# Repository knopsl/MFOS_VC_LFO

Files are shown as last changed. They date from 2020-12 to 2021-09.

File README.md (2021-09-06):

# MFOS VC LFO sync mod, pulse width fix, and Kosmo panel

This is a couple of modifications for the MFOS VC LFO and a Kosmo format front panel. One mod is component value changes, described below, that correct some undesired behavior having to do with the pulse width. The other is an auxiliary PCB that adds a sync input as well as a Euro/Kosmo style power header.

## Sync input

The auxiliary board adds a sync input. A rising edge on this input resets the LFO's triangle core to either the maximum or the minimum peak (switch selectable). This allows LFO modulation to begin in sync with e.g. the start of a note. Other outputs also are synced at either the "beginning" or the "midpoint" (in time) of the waveform.

This modification is based on Tim Parkhurst's [sync mod](https://electro-music.com/forum/post-387749.html#387749).  I added a switch to select whether to charge the triangle core to its maximum or minimum value, affecting where in each waveform sync occurs. Resistances were changed to accommodate the MFOS LFO's larger integrating capacitor, and I used J113 for the JFET instead of 2N3819. 2N5458 was also found to work, J112 did not. One resistor was made a trimmer to allow tuning the voltage to which the oscillator resets. It should be adjusted until the triangle wave is at its maximum or minimum immediately after syncing.

The auxiliary board also has footprints for a Eurorack style power header with reversal protection diodes and bypass capacitors (which should be mounted there instead of on the MFOS board) and a terminal block. Wires from the terminal block connect to ±12 V and ground on the MFOS board. Molex connectors are used to connect the sync mod to the panel controls and PCB.

## Pulse width fixes

As designed, the MFOS LFO has some undesireable behavior with the pulse width. The PW CV input floats when nothing is plugged in, meaning that the pulse width and its range are different with no CV input versus with 0V CV input. Also, since the PW pot and its associated fixed resistors are large compared to the summing resistors, an attenuator on the PW CV (external or added to the front panel) will affect the behavior of the pulse width pot and vice versa.

I recommend the following changes:

* R37 (pulse width pot) from 100k to 25k
* R36 and R42 (fixed resistors at ends of R37) from 100k to 3.3k
* R58 and R59 (summing resistors) from 10k to 200k

With these changes I find the effects of the PW pot on the PW CV attenuator and vice versa are negligible, and I get a pulse width range from the knob (with no CV) of about 7% to 91%. 

## Front panel

A Kosmo format front panel is also provided. It includes space for the attenuator pots for the FM 1 and PWM control voltages. Width is 10 cm.

## Sync mod documentation

* [Build notes](Docs/build_notes.md) 
* [BOM](Docs/MFOS_VCLFO_aux.pdf) (See above for changes to the main PCB BOM.)
* [Schematics](Docs/MFOS_VCLFO_aux.pdf) 

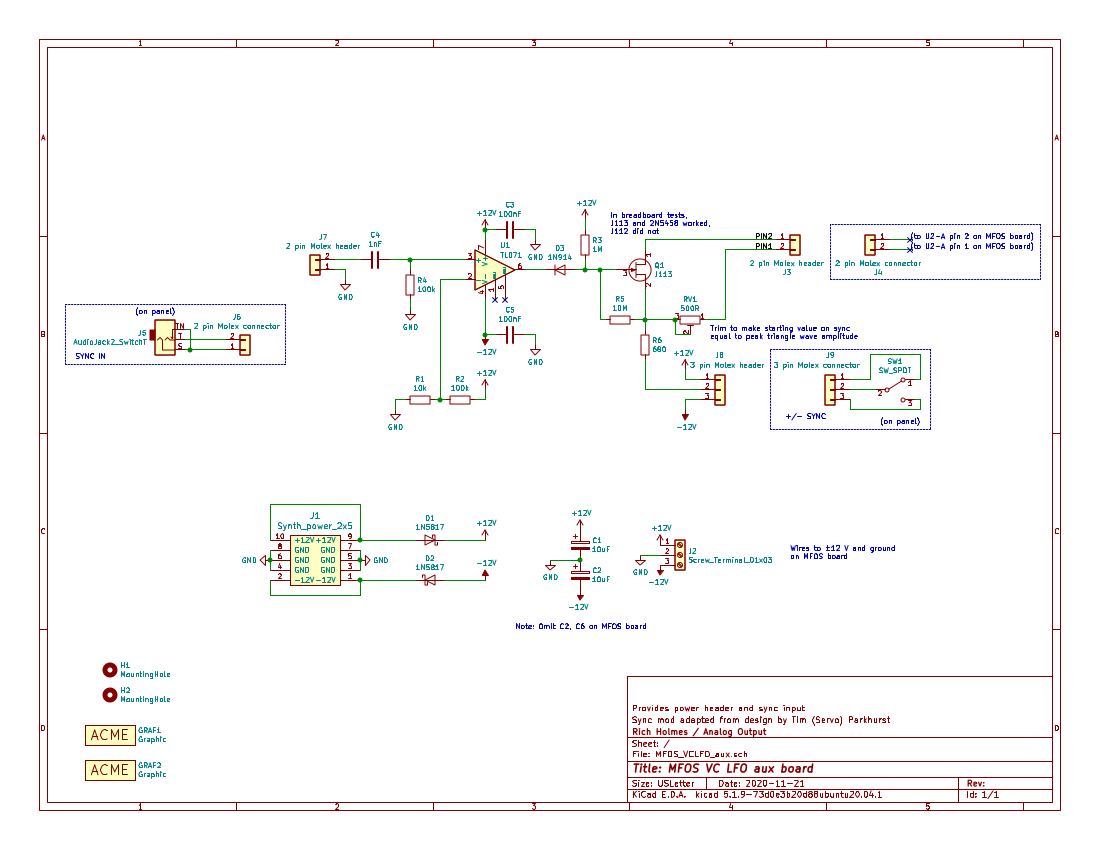
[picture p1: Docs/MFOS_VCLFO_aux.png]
Auxiliary PCB

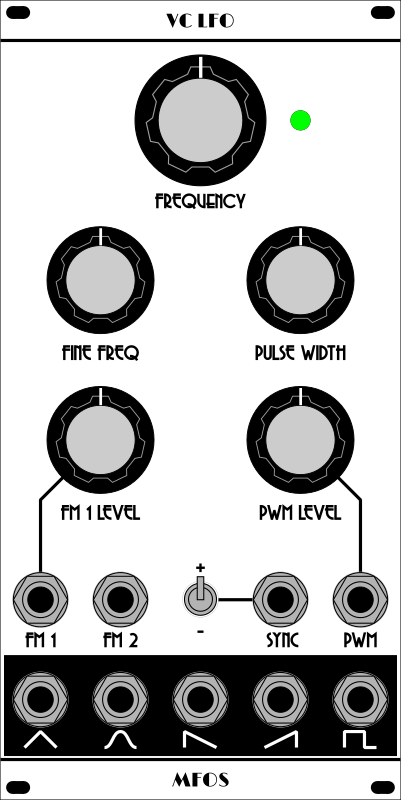
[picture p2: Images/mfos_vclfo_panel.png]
Kosmo front panel


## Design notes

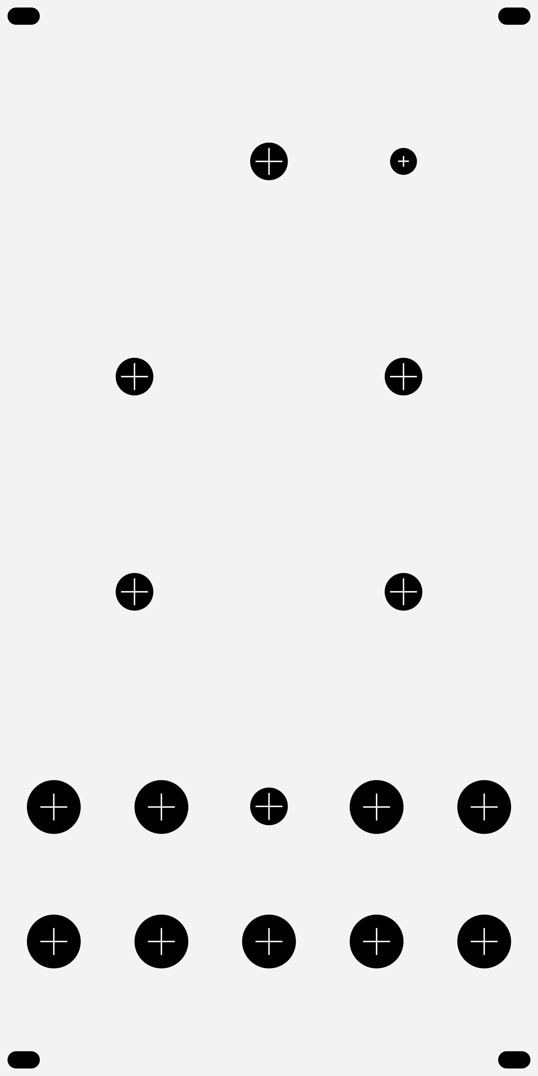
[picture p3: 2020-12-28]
Hardware/Panel/mfos_vclfo_panel_holes.png

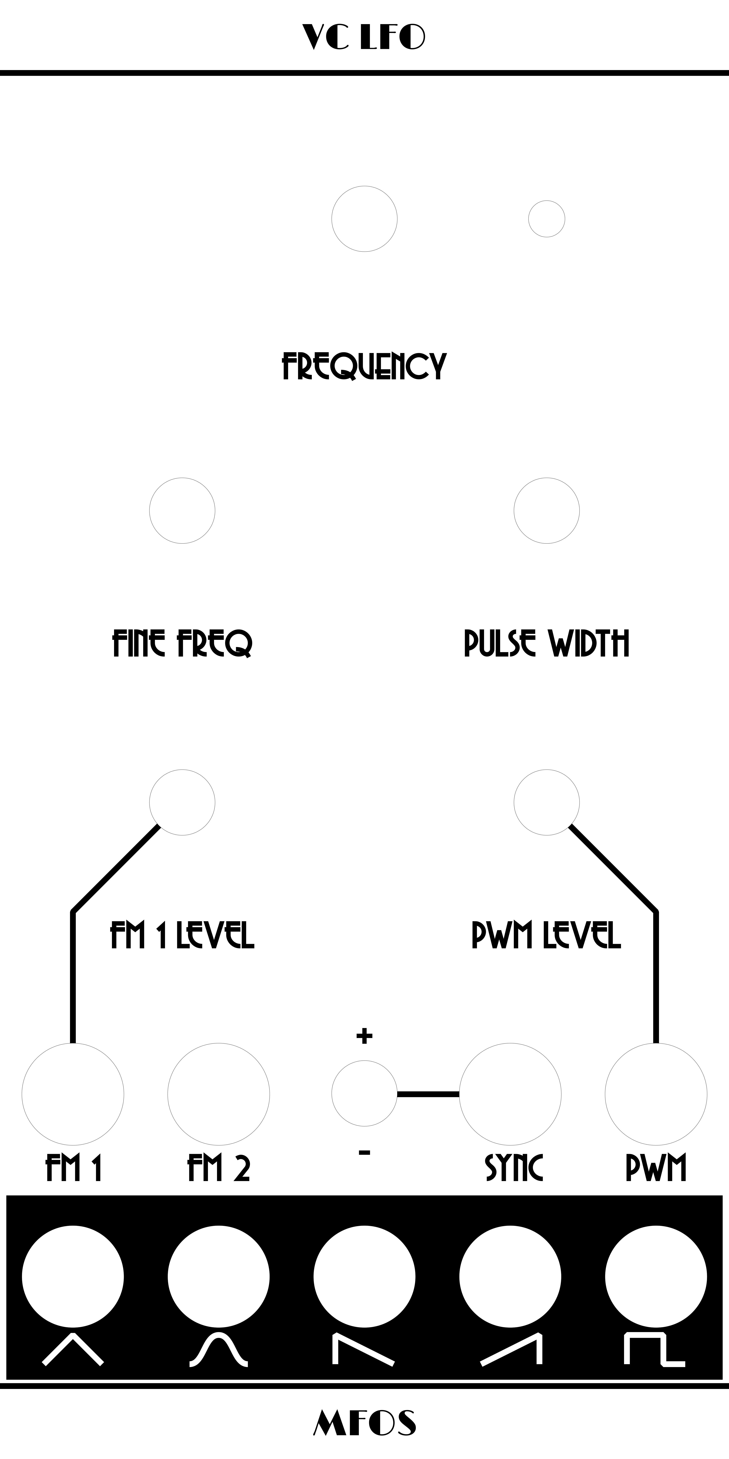
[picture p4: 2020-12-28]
Images/mfos_vclfo_panel_art.png

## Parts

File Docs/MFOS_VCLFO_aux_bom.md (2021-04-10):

# Auxiliary board for MFOS VC LFO BOM

Wed 31 Mar 2021 05:28:39 PM EDT

Generated from schematic by Eeschema 5.1.9-73d0e3b20d~88~ubuntu20.04.1

**Component Count:** 27

| Refs | Qty | Component | Description | Manufacturer | Part | Vendor | SKU |
| ----- | --- | ---- | --- | ---- | ---- | ---- | ---- |
| C1, C2 | 2 | 10uF | Electrolytic capacitor |  |  | Tayda | A-4349 |
| C3, C5 | 2 | 100nF | Ceramic capacitor |  |  | Tayda | A-553 |
| C4 | 1 | 1nF | Polyester film capacitor |  |  | Tayda | A-1531 |
| D1, D2 | 2 | 1N5817 | Schottky diode |  |  | Tayda | A-159 |
| D3 | 1 | 1N914 | 100V 0.3A Small Signal Fast Switching Diode, DO-35 |  |  | Tayda | A-157 |
| J1 | 1 | Synth_power_2x5 | 2x5 pin shrouded header 2.54 mm spacing |  |  | Tayda | A-2939 |
| J2 | 1 | Screw_Terminal_01x03 | Screw terminal, single row, 01x03 | Degson | DG301 | Tayda | A-669 |
| J3, J7 | 2 | 2 pin Molex header | 2 pin Molex header 2.54 mm spacing |  |  | Tayda | A-804 |
| J4, J6 | 2 | 2 pin Molex connector | 2 pin Molex connector 2.54 mm spacing |  |  | Tayda | A-826 |
| J5 | 1 | AudioJack2_SwitchT | Audio Jack, 2 Poles (Mono / TS), Switched T Pole (Normalling) |  |  | Tayda | A-1121 |
| J8 | 1 | 3 pin Molex header | 3 pin Molex header 2.54 mm spacing |  |  | Tayda | A-805 |
| J9 | 1 | 3 pin Molex connector | 3 pin Molex connector 2.54 mm spacing |  |  | Tayda | A-827 |
| Q1 | 1 | J113 | N-JFET transistor, drain/source/gate |  |  | Digi-Key | J113FS-ND |
| R1 | 1 | 10k | Resistor |  |  | Tayda |  |
| R2, R4 | 2 | 100k | Resistor |  |  | Tayda |  |
| R3 | 1 | 1M | Resistor |  |  | Tayda |  |
| R5 | 1 | 10M | Resistor |  |  | Tayda |  |
| R6 | 1 | 680 | Resistor |  |  | Tayda |  |
| RV1 | 1 | 500R | Trim-potentiometer | Alpha | 3296W | Tayda | A-596 |
| SW1 | 1 | SW_SPDT | Switch, single pole double throw |  |  | Tayda | A-3186 |
| U1 | 1 | TL071 | Single Low-Noise JFET-Input Operational Amplifiers, DIP-8 |  |  | Tayda | A-1135 |
| | 1 | | 8 pin DIP socket | | | |

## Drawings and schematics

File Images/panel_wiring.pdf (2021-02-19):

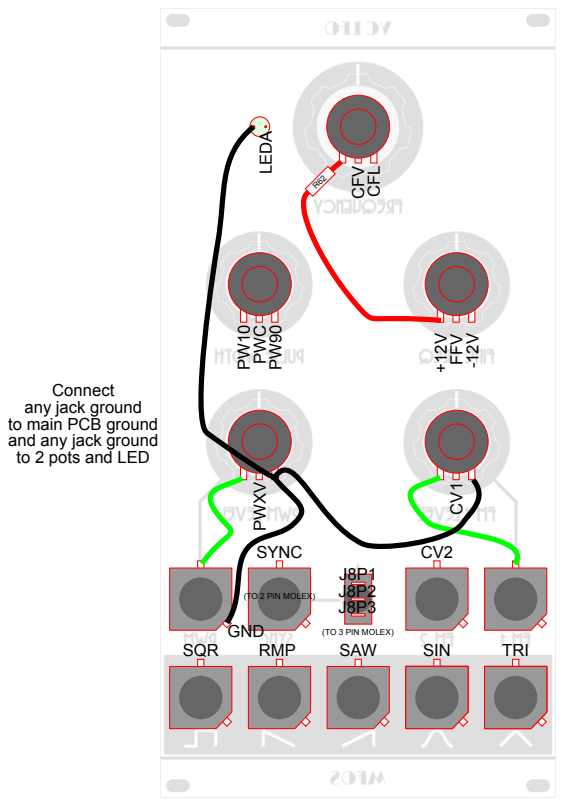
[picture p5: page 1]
+12V FFV; CFV; CFL; LEDA; PWC PWXV; SYNC; SQR; SAWRMP; TRISIN

Connect
any jack ground
to main PCB ground
and any jack ground
to 2 pots and LED

(TO 2 PIN MOLEX)
GND

(TO 3 PIN MOLEX)

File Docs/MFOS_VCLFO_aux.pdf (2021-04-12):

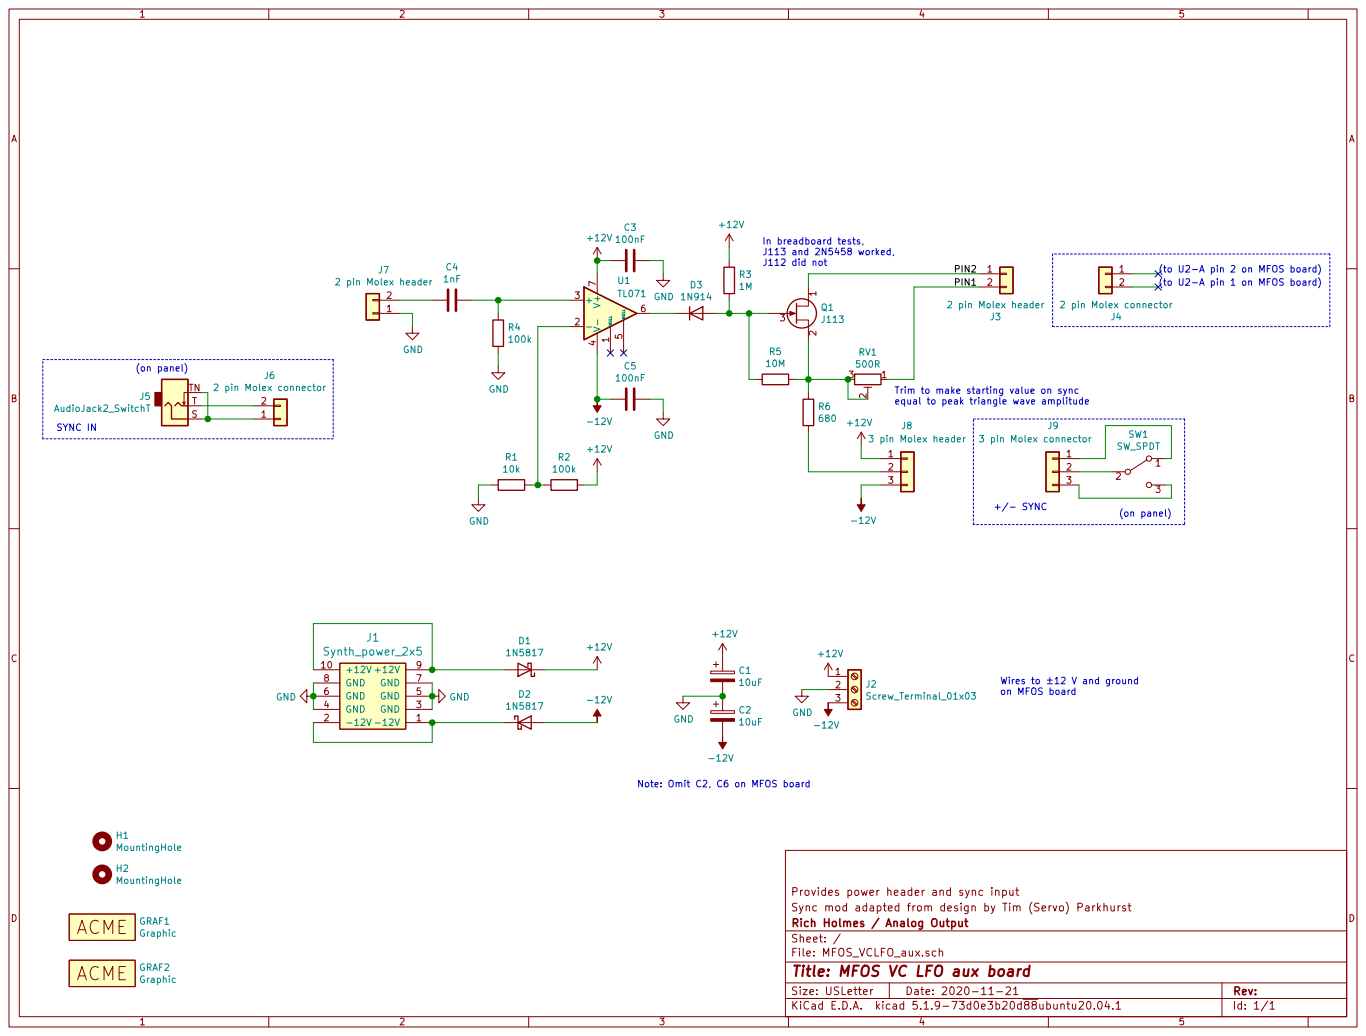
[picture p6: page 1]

(to U2-A pin 2 on MFOS board)
(to U2-A pin 1 on MFOS board)

Trim to make starting value on sync
equal to peak triangle wave amplitude

Wires to ±12 V and ground on MFOS board

Provides power header and sync input
Sync mod adapted from design by Tim (Servo) Parkhurst
File: MFOS_VCLFO_aux.sch Sheet: / Rich Holmes / Analog Output

Id: 1/1 Title: MFOS VC LFO aux board

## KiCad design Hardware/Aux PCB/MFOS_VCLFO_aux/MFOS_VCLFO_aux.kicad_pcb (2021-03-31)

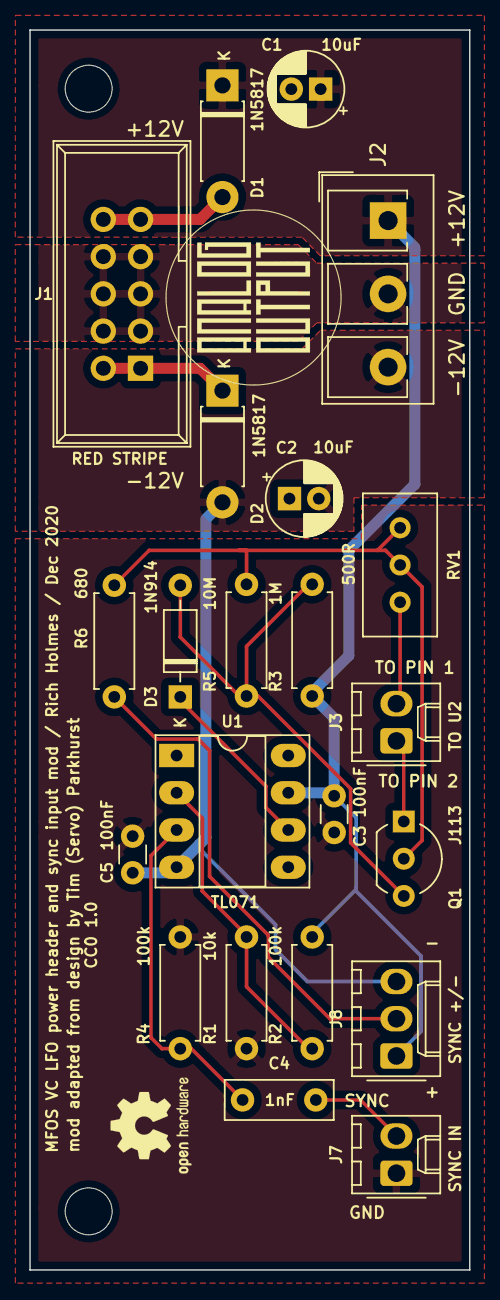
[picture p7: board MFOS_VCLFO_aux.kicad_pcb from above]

Board: 2 copper layers, 30.0 x 84.6 mm, 26 parts (0 on the bottom side), 14 nets.

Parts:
C1, C2: 10uF; CP_Radial_D5.0mm_P2.00mm
C3, C5: 100nF; C_Disc_D3.0mm_W1.6mm_P2.50mm
C4: 1nF; C_Rect_L7.2mm_W2.5mm_P5.00mm_FKS2_FKP2_MKS2_MKP2
D1, D2: 1N5817; D_DO-41_SOD81_P7.62mm_Horizontal
D3: 1N914; D_DO-35_SOD27_P7.62mm_Horizontal
GRAF1: Graphic; analogoutput_12mm
GRAF2: Graphic; OSHW-Logo2_7.3x6mm_SilkScreen
H1, H2: MountingHole; MountingHole_3.2mm_M3
J1: Synth_power_2x5; Power_Header
J2: Screw_Terminal_01x03; TerminalBlock_Degson_DG301_1x03_P5.00mm_Vertical
J3, J7: 2 pin Molex header; Molex_KK-254_AE-6410-02A_1x02_P2.54mm_Vertical
J8: 3 pin Molex header; Molex_KK-254_AE-6410-03A_1x03_P2.54mm_Vertical
Q1: J113; TO-92_Inline_Wide
R1: 10k; R_Axial_DIN0207_L6.3mm_D2.5mm_P7.62mm_Horizontal
R2, R4: 100k; R_Axial_DIN0207_L6.3mm_D2.5mm_P7.62mm_Horizontal
R3: 1M; R_Axial_DIN0207_L6.3mm_D2.5mm_P7.62mm_Horizontal
R5: 10M; R_Axial_DIN0207_L6.3mm_D2.5mm_P7.62mm_Horizontal
R6: 680; R_Axial_DIN0207_L6.3mm_D2.5mm_P7.62mm_Horizontal
RV1: 500R; Potentiometer_Bourns_3296W_Vertical
U1: TL071; DIP-8_W7.62mm_Socket_LongPads

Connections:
+12V: C1.1, C3.2, D1.1, J2.1, J8.1, R2.2, R3.1, U1.7
-12V: C2.2, C5.2, D2.2, J2.3, J8.3, U1.4
/PIN1: J3.2, RV1.1
/PIN2: J3.1, Q1.1
GND: C1.2, C2.1, C3.1, C5.1, J1.3, J1.4, J1.5, J1.6, J1.7, J1.8, J2.2, J7.1, R1.1, R4.2
unnamed: C4.1, R4.1, U1.3
unnamed: C4.2, J7.2
unnamed: D1.2, J1.9, J1.10
unnamed: D2.1, J1.1, J1.2
unnamed: D3.1, U1.6
unnamed: D3.2, Q1.3, R3.2, R5.1
unnamed: J8.2, R6.2
unnamed: Q1.2, R5.2, R6.1, RV1.2, RV1.3
unnamed: R1.2, R2.1, U1.2

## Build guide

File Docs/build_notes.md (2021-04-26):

# MFOS VC LFO sync mod build notes

Reversal protection diodes and bypass capacitors should be mounted on the auxiliary board, the latter in place of the ones on the MFOS board, where they are C2 and C6. Wires from the terminal block connect to ±12 V and ground on the MFOS board. Wires from a 2-pin Molex connector connect to U2-A pins 1 and 2 on the MFOS board. Panel controls (SYNC IN jack and SYNC +/- switch) connect to the auxiliary board via Molex connectors.

The front panel includes space for the attenuator pots for the FM 1 and PWM control voltages. Use 100k for FM 1 CV and 25k for PWM CV. See [wiring diagram](../Images/panel_wiring.pdf) and images below for how to connect attenuators to CV inputs and PCB.

Look at the triangle wave output on a scope, plug a low frequency square wave into the Sync input and trigger your scope on the rising edge of that. You should see a discontinuity in the triangle wave at the moment of the sync. Adjust the trimmer to make the triangle wave start at its minimum (switch in - position) or maximum (+ position) amplitude. If you don't have a scope, use the triangle wave to modulate an oscillator frequency and you should be able to trim it reasonably well.

## Connection images

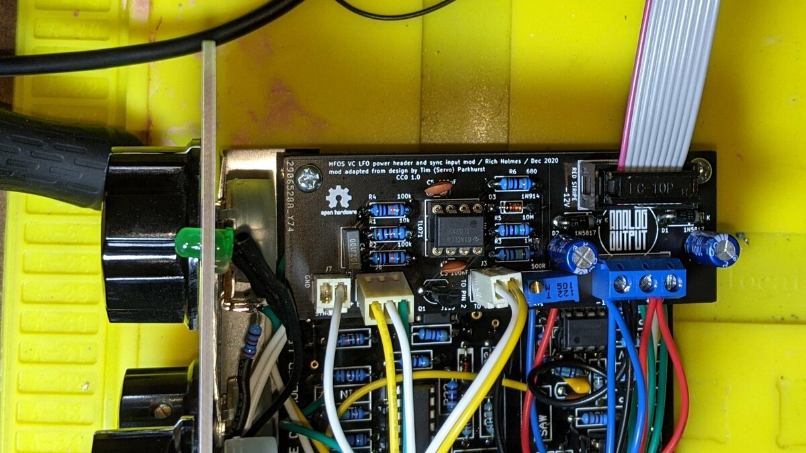
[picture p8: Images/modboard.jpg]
Sync mod board

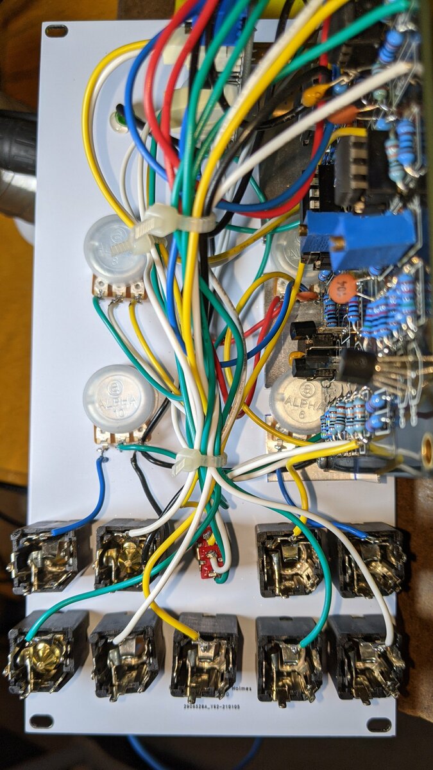
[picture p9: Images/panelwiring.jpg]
Panel wiring

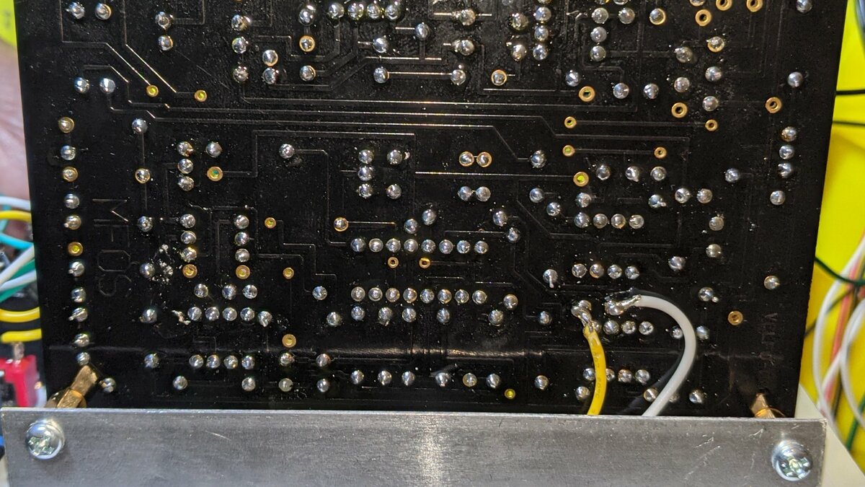
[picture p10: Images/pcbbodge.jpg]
PCB connection


* [Wiring diagram](../Images/panel_wiring.pdf)

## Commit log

2020-12-28 Initial version
    [MFOS_VCLFO_aux-B_Cu.gbr, MFOS_VCLFO_aux-B_Mask.gbr, MFOS_VCLFO_aux-B_Paste.gbr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]
2021-01-17 Include lib table files; new Gerbers
    [MFOS_VCLFO_aux-B_Cu.gbr, MFOS_VCLFO_aux-B_Mask.gbr, MFOS_VCLFO_aux-B_Paste.gbr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]
2021-02-13 BOM and some symbol work, .gitignore_extra
    [MFOS_VCLFO_aux.kicad_pcb]
2021-03-02 Make C4 film, correct dumbass op amp topology
    [MFOS_VCLFO_aux-B_Cu.gbr, MFOS_VCLFO_aux-B_Mask.gbr, MFOS_VCLFO_aux-B_Paste.gbr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]
2021-03-02 Add some PCB labels
    [MFOS_VCLFO_aux-B_Cu.gbr, MFOS_VCLFO_aux-B_Mask.gbr, MFOS_VCLFO_aux-B_Paste.gbr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]
2021-03-31 Final revisions before fabrication
    [MFOS_VCLFO_aux-B_Cu.gbr, MFOS_VCLFO_aux-B_Mask.gbr, MFOS_VCLFO_aux-B_Paste.gbr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]
2021-04-10 BOM updates
2021-04-14 Revised Gerbers
    [mfos_vclfo_panel-B_Cu.gbr, mfos_vclfo_panel-B_Mask.gbr, mfos_vclfo_panel-B_Paste.gbr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]
2021-04-24 Move images, add link to wiring diagram to READMS
